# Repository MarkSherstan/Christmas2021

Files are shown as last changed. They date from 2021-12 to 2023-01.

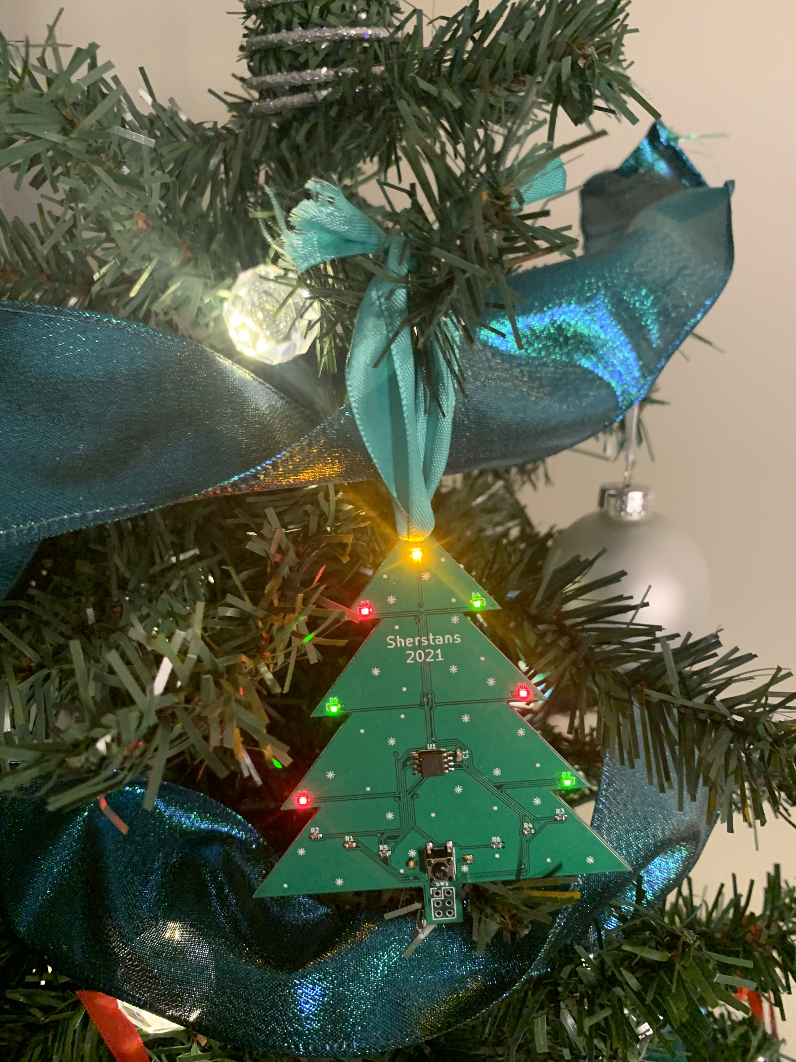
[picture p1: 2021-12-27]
Photos/Final.JPG

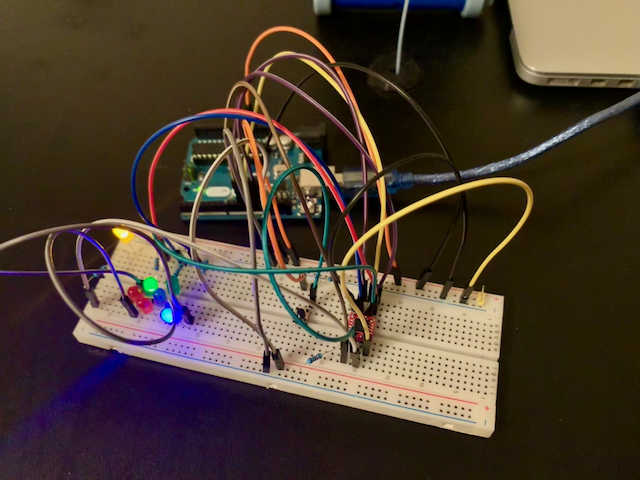
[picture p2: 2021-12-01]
Photos/Breadboard.png

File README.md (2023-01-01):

# Christmas 2021
Hardware and firmware project for the 2021 holiday season

# How to Use
1. Put 2x AAA batteries in holder on the back of ornament (place batteries with correct polarity or the board might catch on fire)
2. Press button to see 1 of 5 patterns

Other notes:
* This item 100% contains lead
* The batteries should last somewhere between one week and a year or two (multimeter was not accurate enough to get a real number but its been running for at least a week - update: 1+ year battery life has been reported)
* The board is not conformal coated meaning all contacts are "live". Therefore, make sure the board does not make contact with any metal objects (this will cause magic smoke; not good)
* Do your best to hold the PCB by the edges. This reduces the risk of static discharge which tends to put electrical components in the graveyard

# AS IS
THE SOFTWARE AND HARDWARE IS PROVIDED “AS IS”, WITHOUT WARRANTY OF ANY KIND, EXPRESS OR IMPLIED, INCLUDING BUT NOT LIMITED TO THE WARRANTIES OF MERCHANTABILITY, FITNESS FOR A PARTICULAR PURPOSE AND NONINFRINGEMENT. IN NO EVENT SHALL THE AUTHORS OR COPYRIGHT HOLDERS BE LIABLE FOR ANY CLAIM, DAMAGES OR OTHER LIABILITY, WHETHER IN AN ACTION OF CONTRACT, TORT OR OTHERWISE, ARISING FROM, OUT OF OR IN CONNECTION WITH THE SOFTWARE OR THE USE OR OTHER DEALINGS IN THE SOFTWARE.

# Software Requirements
Only required for changing design files
 
## Firmware
* Arduino IDE version 1.18.3 or greater
* In preferences add https://raw.githubusercontent.com/damellis/attiny/ide-1.6.x-boards-manager/package_damellis_attiny_index.json to `Additional Boards Manager URLs`
* Add ATtiny under `Boards Manager` and then configure the following settings:
- Board: ATtiny25/45/85
- Processor: ATtiny85
- Clock: Internal 8 MHz

Program over ICSP (will need a 2nd microcontroller acting as master)

## Hardware 
Boards designed in KiCad 5 and manufactured at JLCPCB

## Other
See all source code and design files at https://github.com/MarkSherstan/Christmas2021

# Future Ideas
- Double tap to keep pattern on

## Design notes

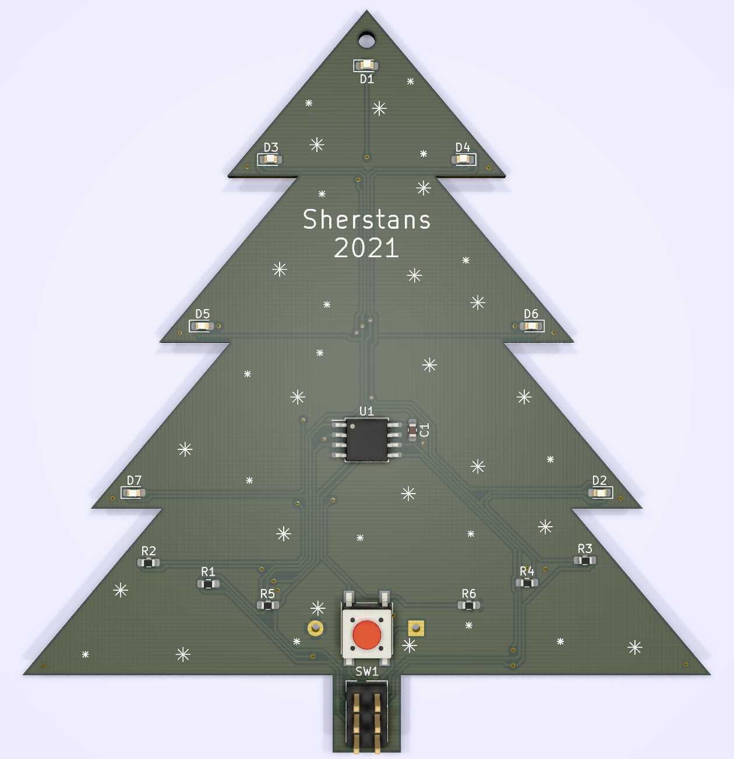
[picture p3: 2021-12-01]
Photos/Render.png

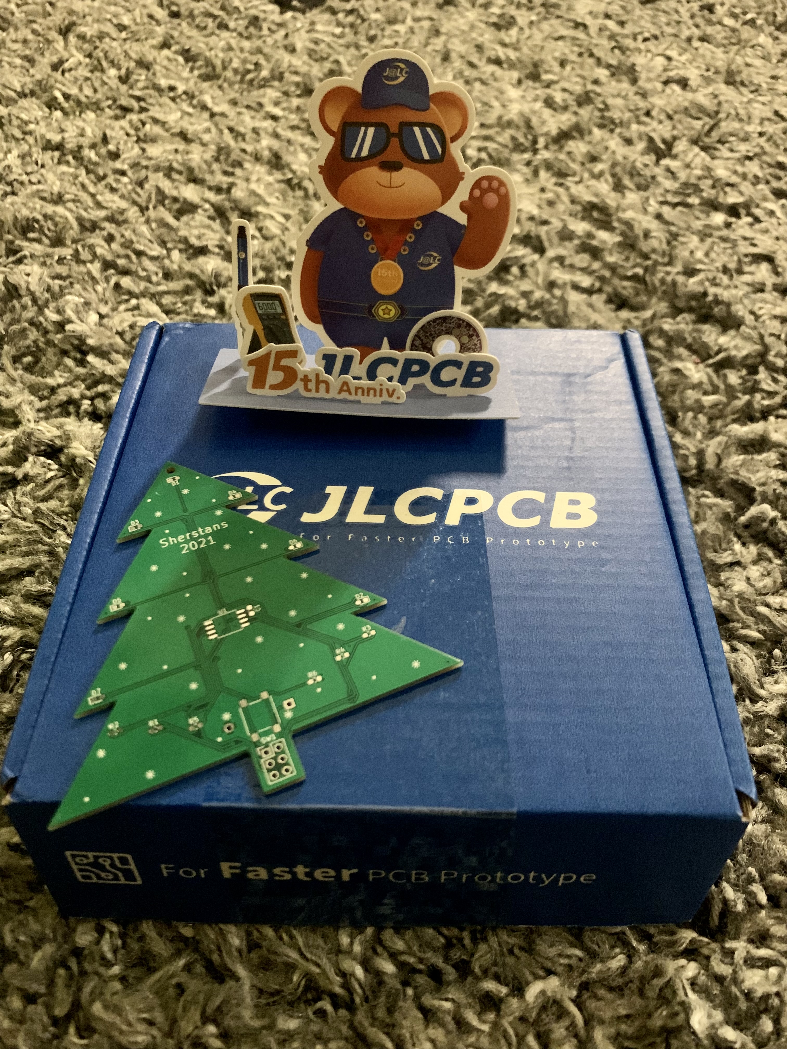
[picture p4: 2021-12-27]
Photos/JLCPCB.JPG

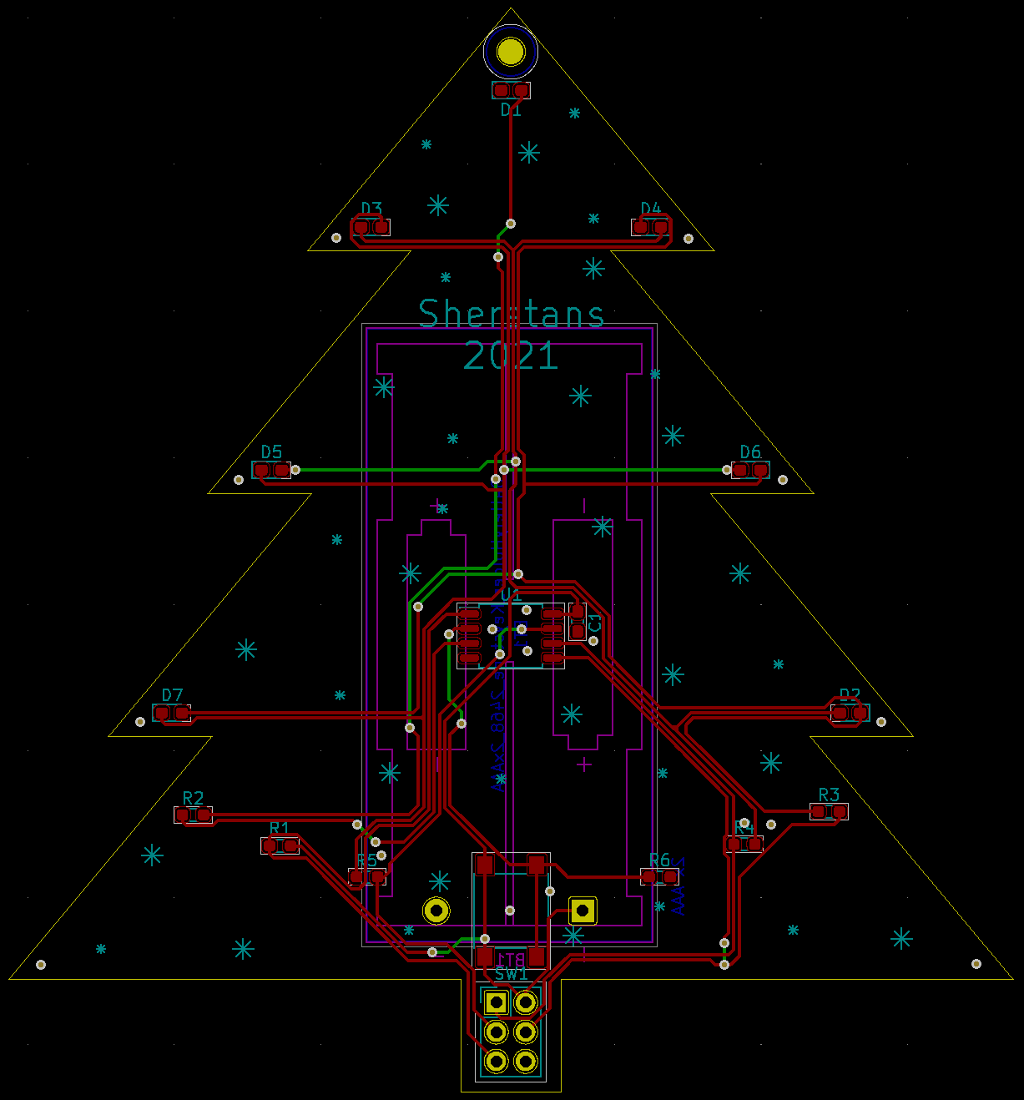
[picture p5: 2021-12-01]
Photos/Raw_Layout.png

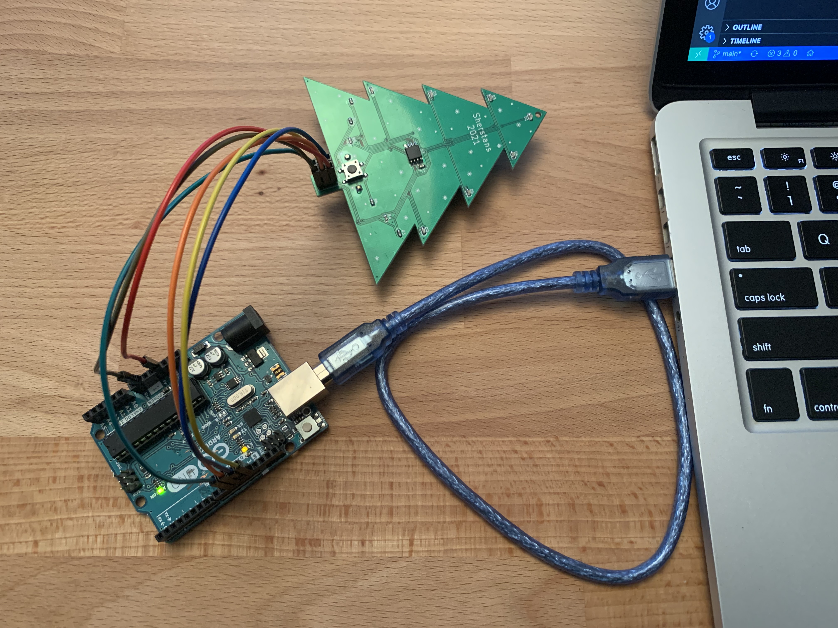
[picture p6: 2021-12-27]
Photos/Programming.JPG

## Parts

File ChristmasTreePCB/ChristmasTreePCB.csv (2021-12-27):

Qty | Reference(s) | Value | LibPart | Footprint | Digi-Key # | Manufacturer | Manufacturer #
1 | BT1 | 2x AAA | Device:Battery_Cell | ChristmasTreeCustomFootprints:2468_Custom | 36-2468-ND | Keystone Electronics | 2468
1 | C1 | 0.1 uF X7R 20% | Device:C | Capacitor_SMD:C_0603_1608Metric_Pad1.08x0.95mm_HandSolder
1 | D1 | Yellow 2.1V 20mA | Device:LED | LED_SMD:LED_0603_1608Metric_Pad1.05x0.95mm_HandSolder
3 | D2, D4, D5 | Green 2V 20mA | Device:LED | LED_SMD:LED_0603_1608Metric_Pad1.05x0.95mm_HandSolder
3 | D3, D6, D7 | Red 2V 20mA | Device:LED | LED_SMD:LED_0603_1608Metric_Pad1.05x0.95mm_HandSolder
1 | H1 | M2 | Mechanical:MountingHole | MountingHole:MountingHole_2.1mm
1 | J1 | ICSP | Connector_Generic:Conn_02x03_Odd_Even | Connector_PinHeader_2.54mm:PinHeader_2x03_P2.54mm_Vertical
2 | R1, R6 | 10 kohm 5% | Device:R | Resistor_SMD:R_0603_1608Metric_Pad0.98x0.95mm_HandSolder
1 | R2 | 62 ohm 5% | Device:R | Resistor_SMD:R_0603_1608Metric_Pad0.98x0.95mm_HandSolder
3 | R3, R4, R5 | 33 ohm 5% | Device:R | Resistor_SMD:R_0603_1608Metric_Pad0.98x0.95mm_HandSolder
1 | SW1 | SPST-NO | Switch:SW_Push | Button_Switch_SMD:SW_SPST_PTS645 | CKN10880CT-ND | C&K | PTS645SL43SMTR92 LFS
1 | U1 | ATtiny85-20SHR | MCU_Microchip_ATtiny:ATtiny85V-10SU | Package_SO:SOIC-8_5.275x5.275mm_P1.27mm | ATTINY85-20SHRCT-ND | Microchip Technology | ATTINY85-20SHR

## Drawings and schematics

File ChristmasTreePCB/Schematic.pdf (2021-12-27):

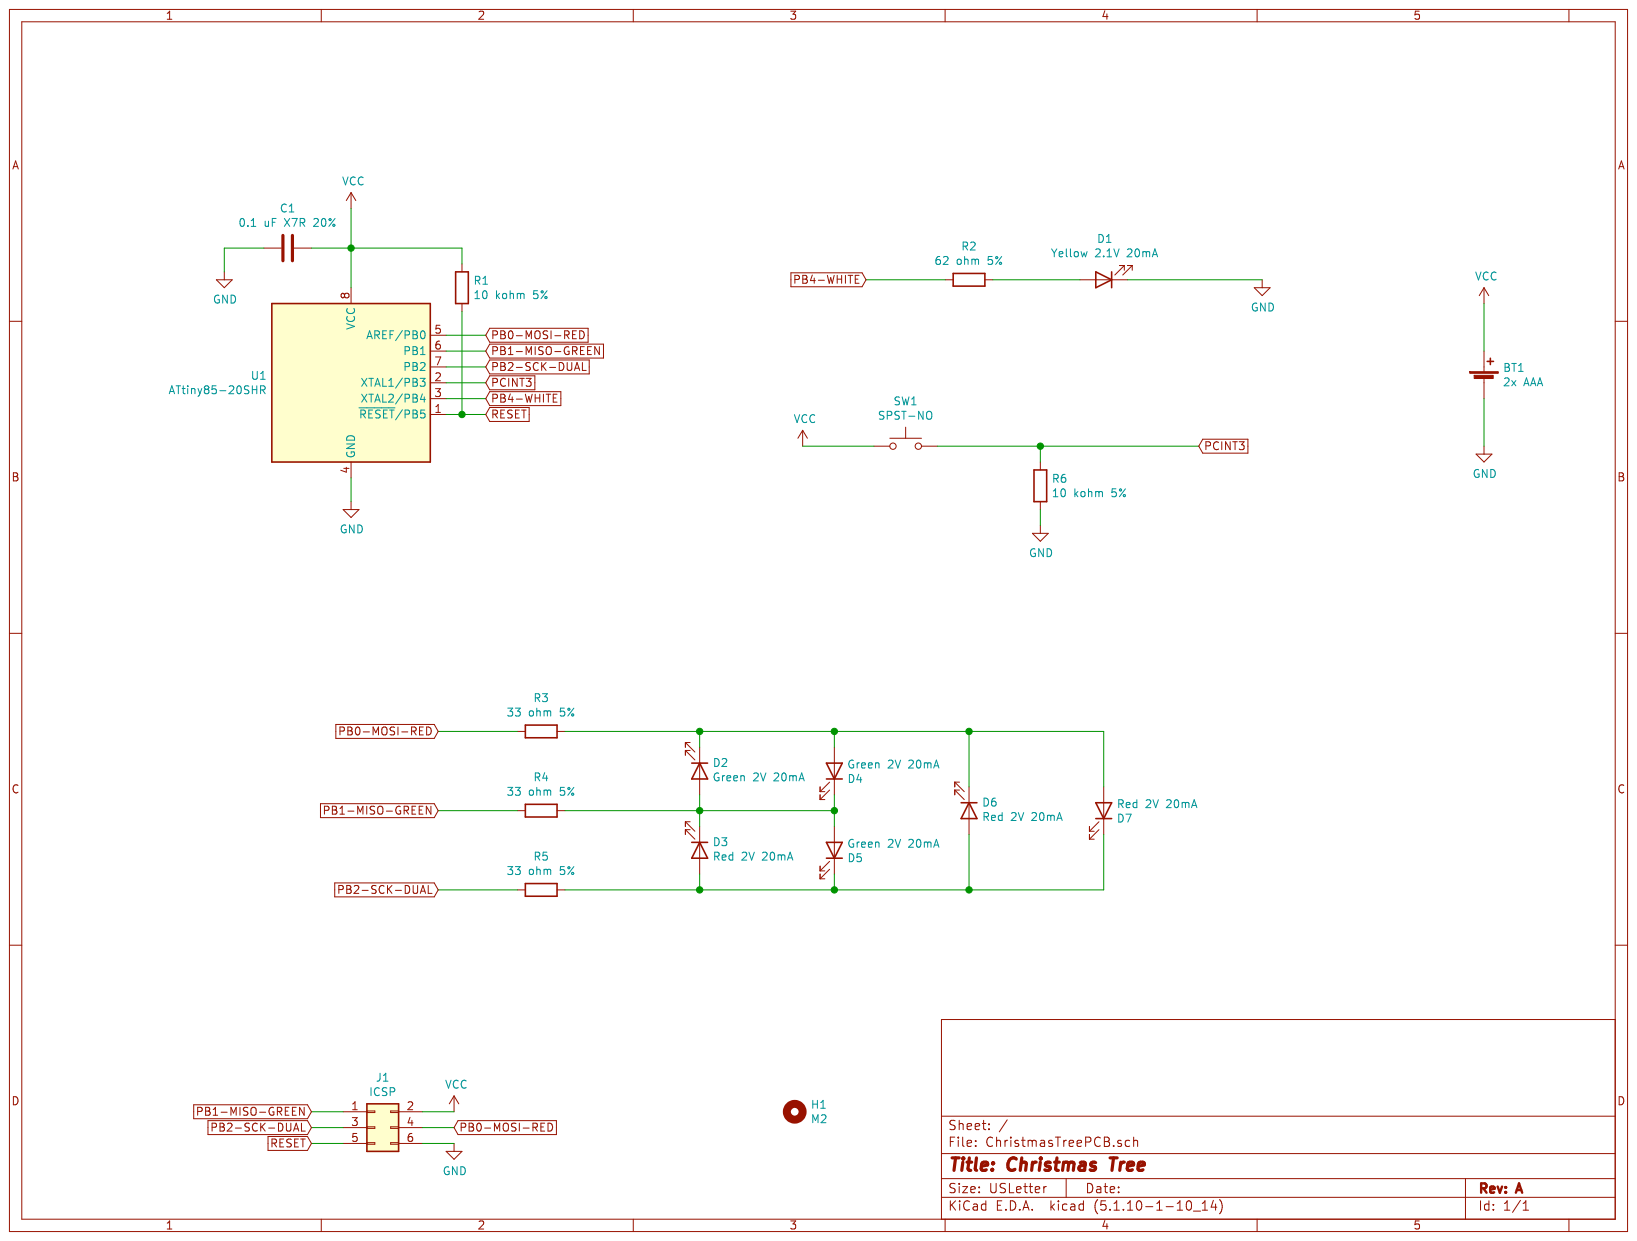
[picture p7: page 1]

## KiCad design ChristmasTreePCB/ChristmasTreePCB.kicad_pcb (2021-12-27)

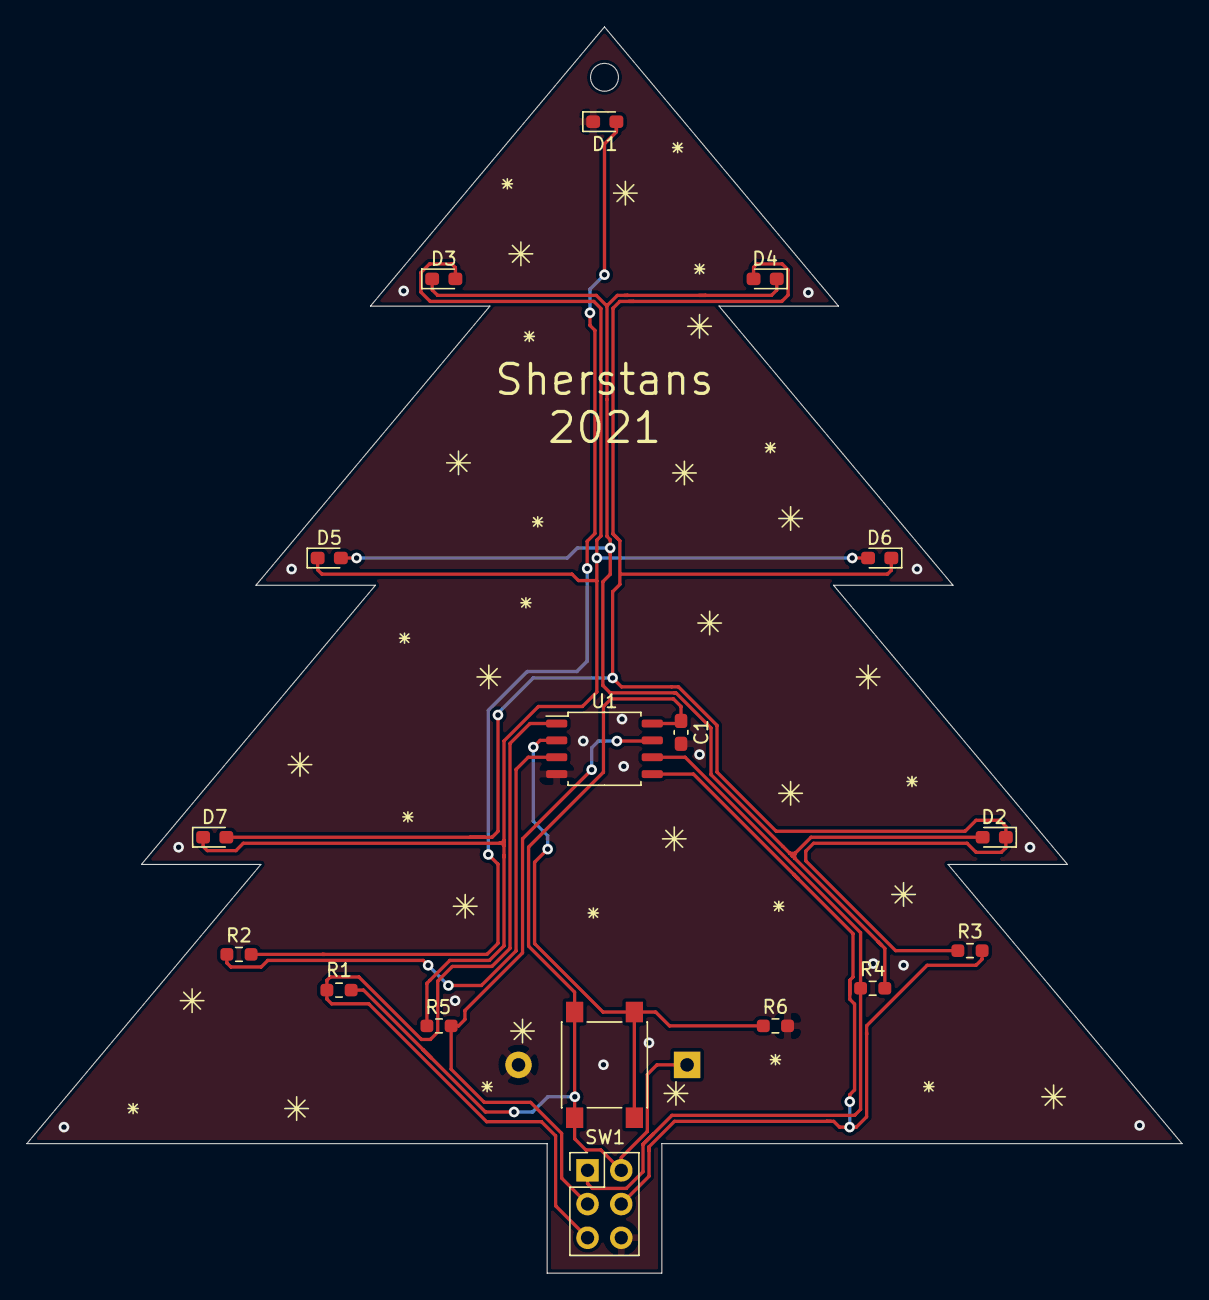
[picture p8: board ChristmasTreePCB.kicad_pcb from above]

Board: 2 copper layers, 87.0 x 93.9 mm, 19 parts (1 on the bottom side), 12 nets.

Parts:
BT1: 2x AAA; 2468_Custom
C1: 0.1 uF X7R 20%; C_0603_1608Metric_Pad1.08x0.95mm_HandSolder
D1: Yellow 2.1V 20mA; LED_0603_1608Metric_Pad1.05x0.95mm_HandSolder
D2, D4, D5: Green 2V 20mA; LED_0603_1608Metric_Pad1.05x0.95mm_HandSolder
D3, D6, D7: Red 2V 20mA; LED_0603_1608Metric_Pad1.05x0.95mm_HandSolder
H1: M2; MountingHole_2.1mm
J1: ICSP; PinHeader_2x03_P2.54mm_Vertical
R1, R6: 10 kohm 5%; R_0603_1608Metric_Pad0.98x0.95mm_HandSolder
R2: 62 ohm 5%; R_0603_1608Metric_Pad0.98x0.95mm_HandSolder
R3, R4, R5: 33 ohm 5%; R_0603_1608Metric_Pad0.98x0.95mm_HandSolder
SW1: SPST-NO; SW_SPST_PTS645
U1: ATtiny85-20SHR; SOIC-8_5.275x5.275mm_P1.27mm

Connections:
GND: BT1.2, C1.1, D1.1, J1.6, R6.2, U1.4
unnamed: D1.2, R2.2
unnamed: D2.1, D4.2, D6.1, D7.2, R3.2
unnamed: D2.2, D3.1, D4.1, D5.2, R4.2
unnamed: D3.2, D5.1, D6.2, D7.1, R5.2
PB0-MOSI-RED: J1.4, R3.1, U1.5
PB1-MISO-GREEN: J1.1, R4.1, U1.6
PB2-SCK-DUAL: J1.3, R5.1, U1.7
PB4-WHITE: R2.1, U1.3
PCINT3: R6.1, SW1.2, U1.2
RESET: J1.5, R1.2, U1.1
VCC: BT1.1, C1.2, J1.2, R1.1, SW1.1, U1.8

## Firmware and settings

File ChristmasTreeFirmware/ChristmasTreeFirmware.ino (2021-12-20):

#include <Arduino.h>
#include <avr/sleep.h>
#include <avr/interrupt.h>
#include "Lights.h"

// Functions
void sleep();

// Class
Lights lights;

// Variables
const uint8_t SWITCH_PIN = 3;
uint8_t state = 0;

// Initialize
void setup()
{
    // Set up button
    pinMode(SWITCH_PIN, INPUT);
    digitalWrite(SWITCH_PIN, HIGH);

    // Initialize the LEDs
    lights.reset();
}

// Run forever
void loop()
{
    // Put processor into a deep sleep waiting for a button press
    sleep();

    // Cycle through the different patterns
    switch (state)
    {
    case 0:
        lights.patternA();
        state += 1;
        break;
    
    case 1:
        lights.patternB();
        state += 1;
        break;
    
    case 2:
        lights.patternC();
        state += 1;
        break;
    
    case 3:
        lights.patternD();
        state += 1;
        break;

    case 4:
        lights.patternE();
        state = 0;
        break;
    
    default:
        state = 0;
        break;
    }
}

// Sleep processor and only wake on button press
void sleep()
{
    // Enable interrupts, turn off ADC, prepare for sleep mode
    GIMSK |= _BV(PCIE);
    PCMSK |= _BV(PCINT3);
    ADCSRA &= ~_BV(ADEN);
    set_sleep_mode(SLEEP_MODE_PWR_DOWN);

    // Enable interrupts and put to sleep
    sleep_enable();
    sei();
    sleep_cpu();

    // Disable interrupts and turn ADC on
    cli();
    PCMSK &= ~_BV(PCINT3);
    sleep_disable();
    ADCSRA |= _BV(ADEN);

    // Enable interrupts
    sei();
}

// Interrupt service routine
ISR(PCINT0_vect) {}

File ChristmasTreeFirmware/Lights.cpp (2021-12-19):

#include "Lights.h"

// Reset all LEDs
void Lights::reset()
{
    pinMode(CHARLIEPLEX_A, INPUT);
    pinMode(CHARLIEPLEX_B, INPUT);
    pinMode(CHARLIEPLEX_C, INPUT);
    pinMode(STAR_LIGHT, OUTPUT);

    digitalWrite(CHARLIEPLEX_A, LOW);
    digitalWrite(CHARLIEPLEX_B, LOW);
    digitalWrite(CHARLIEPLEX_C, LOW);
    digitalWrite(STAR_LIGHT, LOW);
}

// Select LED to turn on
void Lights::lightSelect(uint8_t LED)
{
    pinMode(CHARLIEPLEX_A, stateMatrix[LED][0][0]);
    pinMode(CHARLIEPLEX_B, stateMatrix[LED][0][1]);
    pinMode(CHARLIEPLEX_C, stateMatrix[LED][0][2]);

    digitalWrite(CHARLIEPLEX_A, stateMatrix[LED][1][0]);
    digitalWrite(CHARLIEPLEX_B, stateMatrix[LED][1][1]);
    digitalWrite(CHARLIEPLEX_C, stateMatrix[LED][1][2]);
}

// Select two LEDs to turn on
void Lights::lightSelect2x(uint8_t A, uint8_t B, uint8_t msDelay)
{
    lightSelect(A);
    delay(msDelay);
    lightSelect(B);
    delay(msDelay);
    reset();
}

// Pattern A: Flash all the lights
void Lights::patternA()
{
    // Initial conditions
    uint8_t starBrightness = 255;

    // Loop
    for (uint8_t i = 0; i < 51; i++)
    {
        // Loop through each LED
        for (uint8_t j = 0; j < 6; j++)
        {
            lightSelect(j);
            delay(17);
        }

        // Dim the star light
        starBrightness -= 5;
        analogWrite(STAR_LIGHT, starBrightness);
    }

    // Reset lights
    reset();
}

// Pattern B: Flash up and Down
void Lights::patternB()
{
    // Flash through the tree in groupings
    for (uint8_t i = 0; i < 15; i++)
    {
        for (uint8_t j = 0; j < 4; j++)
        {
            lightSelect2x(1, 4);
        }

        for (uint8_t j = 0; j < 4; j++)
        {
            lightSelect2x(2, 5);
        }

        for (uint8_t j = 0; j < 4; j++)
        {
            lightSelect2x(0, 3);
        }

        digitalWrite(STAR_LIGHT, HIGH);
        delay(100);
        digitalWrite(STAR_LIGHT, LOW);
    }

    // Reset lights
    reset();
}

// Pattern C: Around the world
void Lights::patternC()
{
    // Variables for nice loops
    uint8_t magicDelay = 100;
    uint8_t pins[7] = {4, 2, 3, STAR_LIGHT, 0, 5, 1};

    // Go around the world
    for (uint8_t i = 0; i < 10; i++)
    {
        for (uint8_t j = 0; j < sizeof(pins); j++) 
        {
            if (j == 3) {
                digitalWrite(pins[j], HIGH);
                delay(magicDelay);
                digitalWrite(pins[j], LOW);
            } else {
                lightSelect(pins[j]);
                delay(magicDelay);
            }
        }
    }

    // Reset lights
    reset();
}

// Pattern D: All lights on
void Lights::patternD()
{
    // Turn on the star
    digitalWrite(STAR_LIGHT, HIGH);

    // Loop super fast to make lights all "on"
    for (uint8_t i = 0; i < 250; i++)
    {
        for (uint8_t j = 0; j < 6; j++)
        {
            lightSelect(j);
            delay(2);
        }
    }

    // Reset lights
    reset();
}

// Pattern E: Greens and red lightning
void Lights::patternE()
{
    // Variables for nice loops
    uint8_t magicDelay = 75;
    uint8_t pins[7] = {1, 2, 0, 3, 5, 4};

    // Turn on the star
    digitalWrite(STAR_LIGHT, HIGH);

    // Make a zig zag
    for (uint8_t i = 0; i < 3; i++)
    {
        for (uint8_t ii = 0; ii < 3; ii++)
        {
            for (uint8_t iii = 0; iii < sizeof(pins); iii++) 
            {
                lightSelect(pins[iii]);
                delay(magicDelay);
            }
        }

        // Pulse only the star
        reset();

        for (uint8_t j = 255; j > 0; j--) 
        {
            analogWrite(STAR_LIGHT, j);
            delay(2);
        }

        for (uint8_t k = 0; k < 255; k++) 
        {
            analogWrite(STAR_LIGHT, k);
            delay(2);
        }
    }

    // Reset lights
    for (uint8_t j = 255; j > 0; j--) 
    {
        analogWrite(STAR_LIGHT, j);
        delay(2);
    }
    reset();
}

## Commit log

2021-11-23 40% complete initial schematic
    [ChristmasTreePCB.sch]
2021-11-23 Ignore some cache PCB files
2021-11-24 Add Charlieplexing for LEDs
    [ChristmasTreePCB.sch]
2021-11-24 Schematic 95% done. Need to tidy and footprints
    [ChristmasTreePCB.sch]
2021-11-26 Update brain chip to be SOIC-8
    [ChristmasTreePCB.sch]
2021-11-26 Project and board update
    [ChristmasTreePCB.kicad_pcb]
2021-11-27 All footprints selected
    [ChristmasTreePCB.sch]
2021-11-27 Rough layout
    [ChristmasTreePCB.kicad_pcb, ChristmasTreePCB.sch]
2021-11-27 50% complete routing
    [ChristmasTreePCB.kicad_pcb, ChristmasTreePCB.sch]
2021-11-28 roting complete
    [ChristmasTreePCB.kicad_pcb]
2021-11-28 Clean up routing
    [ChristmasTreePCB.kicad_pcb]
2021-11-28 Pre save before gerbers
    [ChristmasTreePCB.kicad_pcb, ChristmasTreePCB.sch]
2021-11-30 Updated LED colors and R values. Made BOM
    [ChristmasTreePCB.csv, ChristmasTreePCB.kicad_pcb, ChristmasTreePCB.sch]
2021-11-30 Make PDF schematic
2021-12-27 Swap D4 and D6 LED color
    [ChristmasTreePCB.csv, ChristmasTreePCB.kicad_pcb, ChristmasTreePCB.sch]
